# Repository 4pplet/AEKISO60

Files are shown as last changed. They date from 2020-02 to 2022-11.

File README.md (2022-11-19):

# AEKISO60

AEKISO60 is a PCB for use of AEK ISO keycaps in 60% builds, there is some compatibility issues with tray-mount cases due to the AEK ISO layout: Only the mounting hole under space and the ones at the sides can be used. See Altium view of PCB.

## Some features:
- QMK
- USB C
- RGB underglow
- USB horizontal placement is classic GH60, same as GH60, plain60, voyager60 etc.
- ISO AEK Layout support with extensive bottom row support

## Availability:
As an option to DIY, I'll try and keep these available for purchase here: https://4pplet.com/ For DIY, the production files are avaliable in releases.

## Altium view of PCB
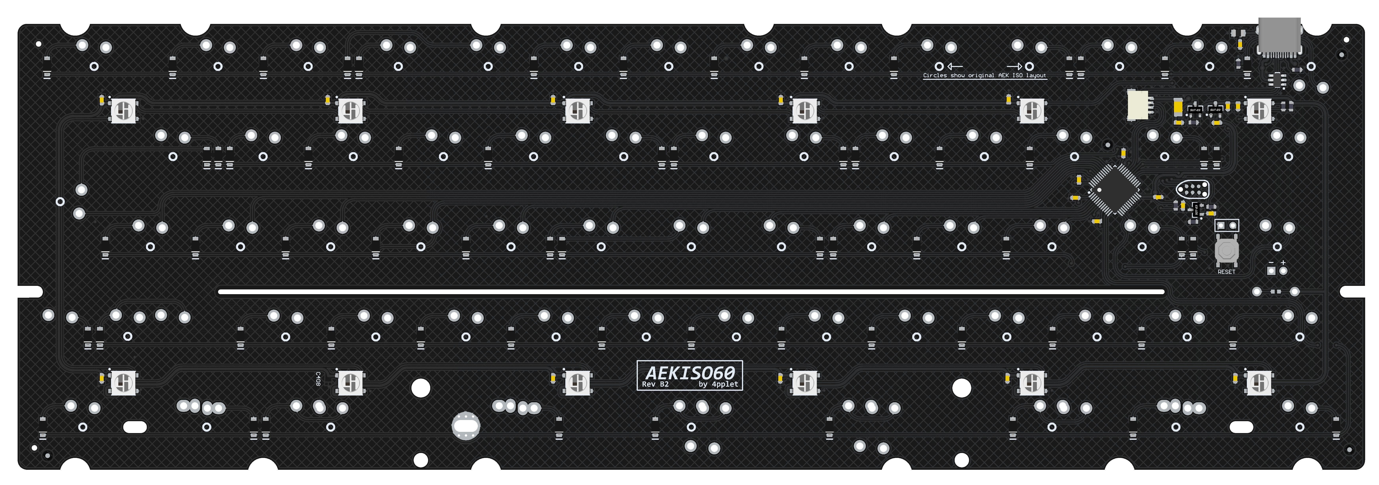
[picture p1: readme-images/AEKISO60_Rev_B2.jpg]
PCB View - Rev B


## Layout support: 
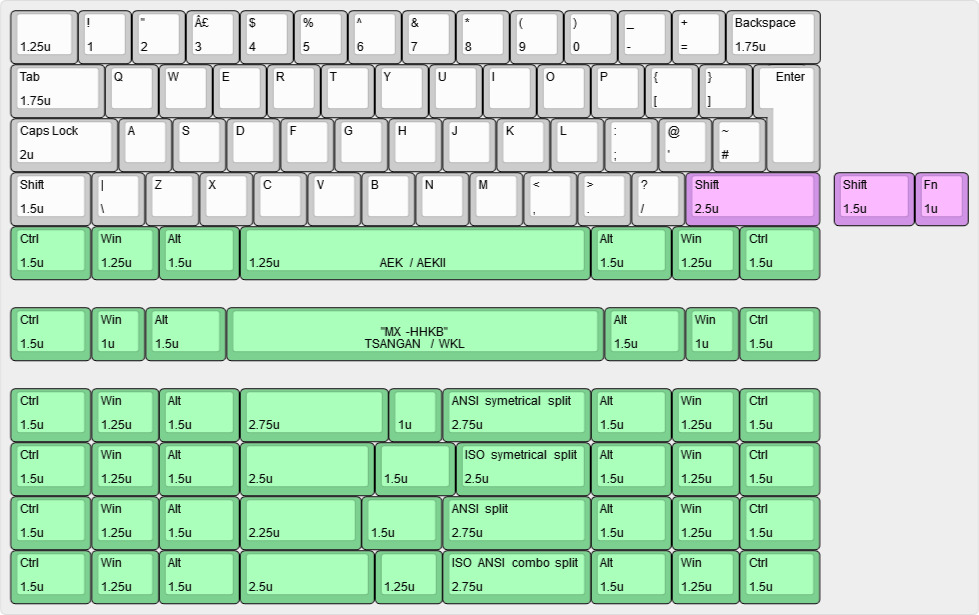
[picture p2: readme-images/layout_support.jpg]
Layout support


## Plate-instruction:
The capslock stabilizer is rotated to give space for the tray-mount screw opening in the plate. Here is a video and picture demonstrating how the stabilizer should be mounted: https://imgur.com/a/tCZg3jl Credits to huygn for making it.

## Revisions:
- Rev A1: Initial prototype
- Rev A2: Improved routing, alligned PCB outline and port position with the other projects. Changed ESD-protection, diodes and XTAL for better compatibility with JLC SMD library.
- Rev A3: Moved daughter board connector to allign with my other 60% projects (same position as cyber60, steezy60 and waffling60-solder)
- Rev A4: Moved daughter board connector for better fitment in bakeneko. Added cutout for bakeneko V3 (untested). Minor siklscreen tweaks.
- Rev B1: Changing MCU to APM/STM32F072, adding LED indicator
- Rev B2: Removing designator left on back side of PCB. Moving LED from FN-switch to Capslock-switch.

<a href='https://ko-fi.com/4pplet' target='_blank'>Buy Me a Coffee at ko-fi.com

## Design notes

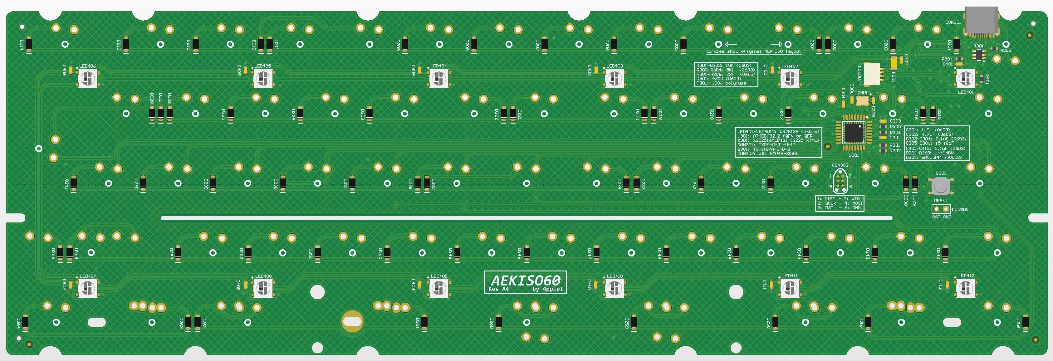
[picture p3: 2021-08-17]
readme-images/AEKISO60_Rev_A4.jpg

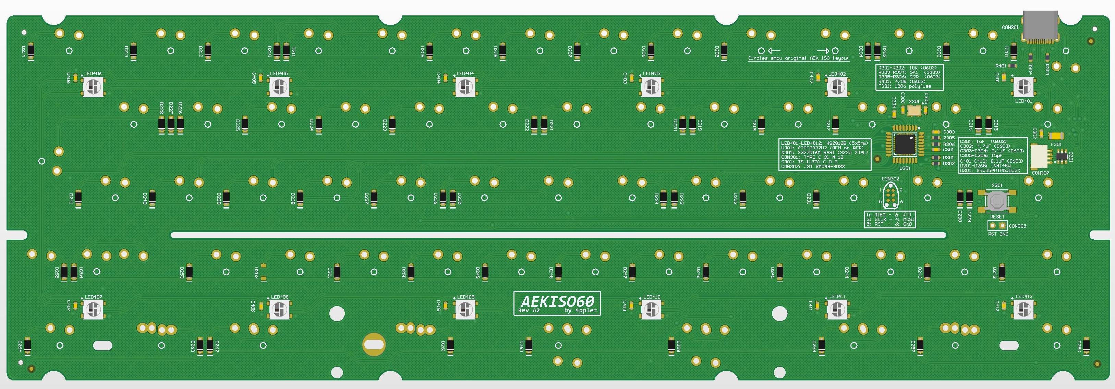
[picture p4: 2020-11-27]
readme-images/AEKISO60_Rev_A2.jpg

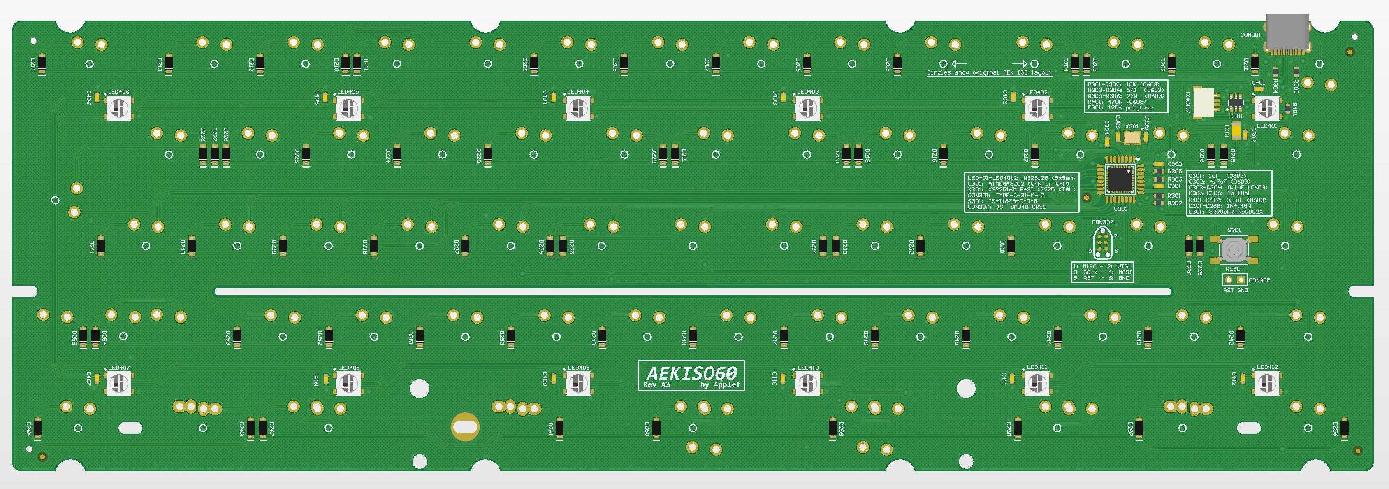
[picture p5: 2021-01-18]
readme-images/AEKISO60_Rev_A3.jpg

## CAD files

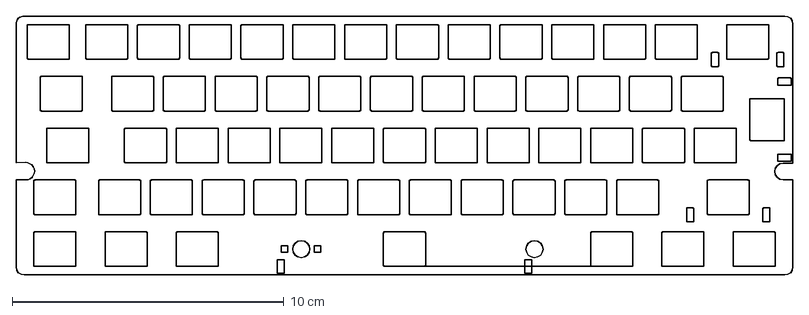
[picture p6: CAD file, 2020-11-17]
AEKISO60_Plate_Rev_A_20201111.dxf
28.6 x 9.53 cm

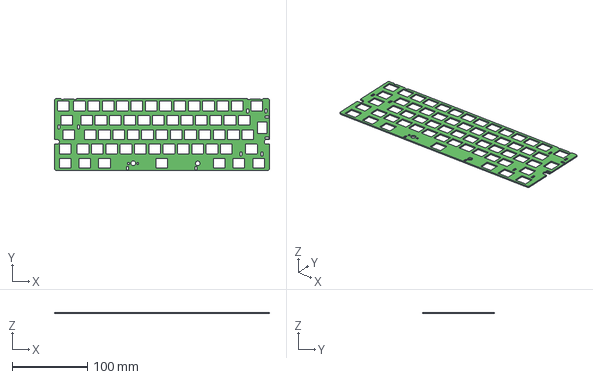
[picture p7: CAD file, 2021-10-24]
Plates/AEKISO60_Plate_Rev_B_FR4.step
285.8 x 95.3 x 1.59 mm

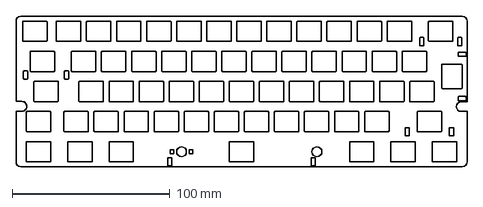
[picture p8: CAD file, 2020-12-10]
Plates/AEKISO60_Plate_Rev_B.dxf
285.8 x 95.2 mm

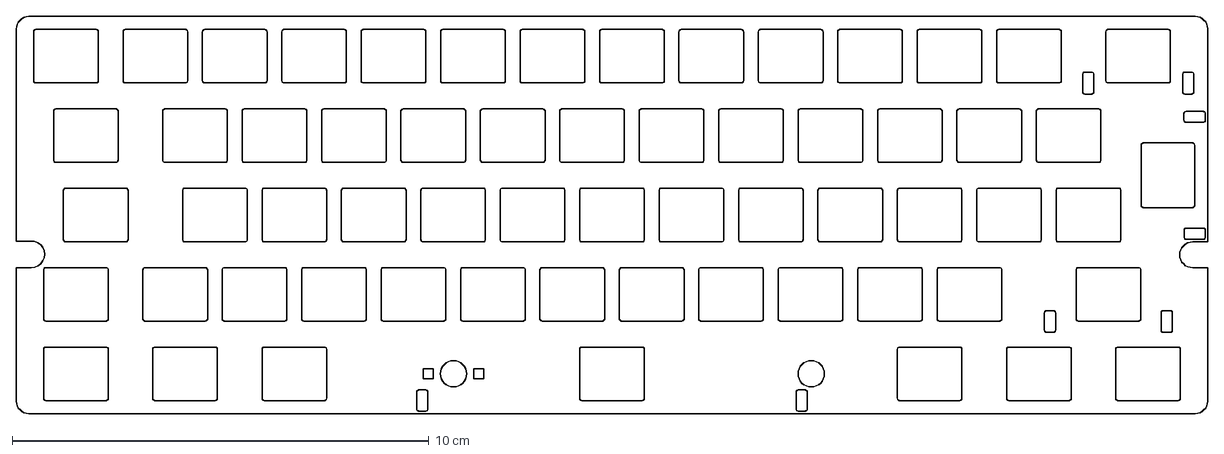
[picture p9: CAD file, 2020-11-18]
Plates/AEKISO60_Plate_Rev_A_20201118.dxf
28.6 x 9.53 cm

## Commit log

2019-11-27 init repo and start
    init repo and start
    [1_top.SchDoc, 2_matrix.SchDoc, 3_mcu.SchDoc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]
2019-12-01 fixed netlist bug, seems to work now
    fixed netlist bug, seems to work now
    [1_top.SchDoc, 2_matrix.SchDoc, AEKISO60.PrjPcb]
2019-12-01 rough implementation done, this should work, need some tidying up
    rough implementation done, this should work, need some tidying up
    [3_mcu.SchDoc, AEKISO60.PcbDoc, AEKISO60.PrjPcb]
2019-12-01 still need to figure out ISO-enter switch position
    still need to figure out ISO-enter switch position
    [2_matrix.SchDoc, AEKISO60.PrjPcb]
2019-12-01 Updated switch and diode numbering, fixed apple logo
    Updated switch and diode numbering, fixed apple logo
    [2_matrix.SchDoc]
2019-12-13 Started to update pinout for underglow leds
    Started to update pinout for underglow leds
    [4_periferals.SchDoc]
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2020-01-16 Started to add JST connector for USB
    Started to add JST connector for USB
    [3_mcu.SchDoc]
2020-01-17 Added LCSC numbers
    Added LCSC numbers
    [3_mcu.SchDoc]
2020-02-03 Updated bottom row with changed layout support
    Updated bottom row with changed layout support
    [2_matrix.SchDoc]
2020-02-04 Files ready for initial prototype
    Files ready for initial prototype
    [AEKISO60.PcbDoc, AEKISO60.PrjPcb]
2020-02-04 Updated BOM
    Updated BOM
    [3_mcu.SchDoc, 4_periferals.SchDoc, AEKISO60.PcbDoc]
2020-02-05 made schematic prettier
    made schematic prettier
    [3_mcu.SchDoc]
2020-02-07 removed second ICSP header, replaced with reset button
    removed second ICSP header, replaced with reset button
    [3_mcu.SchDoc, AEKISO60.PcbDoc]
2020-02-14 added schematic output
    added schematic output
    [3_mcu.SchDoc, AEKISO60.PcbDoc]
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2020-02-22 moved isp pinout on bottom overlay
    moved isp pinout on bottom overlay
    [AEKISO60.PcbDoc]
2020-02-22 updated silkscreen to be in line with other projects
    updated silkscreen to be in line with other projects
    [AEKISO60.PcbDoc]
2020-02-22 moved vias to make silkscreen look better
    moved vias to make silkscreen look better
    [AEKISO60.PcbDoc]
2020-03-08 updated switch-footprint to combo
    updated switch-footprint to combo
    [3_mcu.SchDoc, AEKISO60.PcbDoc]
2020-03-25 Started revision B1, added capslock LED
    Started revision B1, added capslock LED
    [1_top.SchDoc, 2_matrix.SchDoc, 3_mcu.SchDoc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]
2020-03-25 removed THT icsp header and extra reset button
    removed THT icsp header and extra reset button
    [3_mcu.SchDoc, AEKISO60.PcbDoc]
2020-03-25 forgot to save
    forgot to save
    [3_mcu.SchDoc, AEKISO60.PcbDoc]
2020-03-30 removed pad-opening in top-solder for switches, moved usb-connector out a bit
    removed pad-opening in top-solder for switches, moved usb-connector out a bit
    [3_mcu.SchDoc, AEKISO60.PcbDoc]
2020-03-31 started adding flexcut
    started adding flexcut
    [AEKISO60.PcbDoc]
2020-04-01 DRC ok, routing decent. First draft of B1 release
    DRC ok, routing decent. First draft of B1 release
    [AEKISO60.PcbDoc]
2020-04-12 added tooling holes
    added tooling holes
    [AEKISO60.PcbDoc]
2020-04-12 removed tenting
    removed tenting
    [AEKISO60.PcbDoc]
2020-04-23 Restored flex cut, but 1.5mm
    Restored flex cut, but 1.5mm
    [AEKISO60.PcbDoc]
2020-04-24 updated with verified iso enter and removed unaccessible mouting holes
    updated with verified iso enter and removed unaccessible mouting holes
    [AEKISO60.PcbDoc]
2020-04-24 updated parameters and output file, updated readme pic
    updated parameters and output file, updated readme pic
    [2_matrix.SchDoc, 3_mcu.SchDoc, 4_periferals.SchDoc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]
2020-04-24 tweaked routing a bit
    tweaked routing a bit
    [AEKISO60.PcbDoc]
2020-04-26 minor update
    [AEKISO60.PcbDoc]
2020-06-27 tiny tweak
    [AEKISO60.PcbDoc]
2020-06-30 minor tweaks
    [AEKISO60.PcbDoc]
2020-07-09 scrapped B-revision, returning to A
    [1_top.SchDoc, 2_matrix.SchDoc, 3_mcu.SchDoc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]
2020-07-09 DRC ok
    [2_matrix.SchDoc, 3_mcu.SchDoc, AEKISO60.PcbDoc]
2020-07-09 minor tweak
    [AEKISO60.PcbDoc, AEKISO60.PrjPcb]
2020-07-24 started changing diodes to common
    [2_matrix.SchDoc, AEKISO60.PcbDoc]
2020-08-09 DRC OK, should be done for protos
    [AEKISO60.PcbDoc]
2020-09-07 started switching out the diodes
    [2_matrix.SchDoc, 3_mcu.SchDoc, AEKISO60.PcbDoc]
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2020-09-07 DRC ok, diodes replaced
    [2_matrix.SchDoc, AEKISO60.PcbDoc]
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2020-09-21 DRC OK, Rev A2 is pretty much done here.
    [AEKISO60.PrjPcb]
2020-09-21 fixed spacing of underglow leds. DRC OK
2020-09-21 fixed conflicting silkscreen designator
2020-09-23 changed reset switch footprint under space
    [3_mcu.SchDoc, AEKISO60.PrjPcb]
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2020-09-26 added component values, added 3D-model for XTAL
    [3_mcu.SchDoc]
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2020-09-28 changed diode in bom to a more common one
    changed diode in bom to a more common one
    [2_matrix.SchDoc]
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2020-11-18 updated plate, had an extra line
    [AEKISO60_Plate_Rev_A_20201118.dxf]
2020-11-21 minor trace tweak for enter switch and S254
    minor trace tweak for enter switch and S254
    [2_matrix.SchDoc]
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2020-12-01 Create AEKISO60_Plate_Rev_B.dxf
    Includes Caplocks stabs cutouts
    [AEKISO60_Plate_Rev_B.dxf]
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2021-01-08 Updated info on schematic
    [1_top.SchDoc, 2_matrix.SchDoc, 3_mcu.SchDoc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]
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2021-10-01 moving plates into their own dir
    [AEKISO60_Plate_Rev_A_20201118.dxf, AEKISO60_Plate_Rev_B.dxf]
2021-10-24 adding FR4-plate
    adding FR4-plate
    [AEKISO60_Plate_Rev_B_FR4.step]
2022-02-21 moving stuff from keeb-lib into a aekiso60 lib
    [aekiso60.PcbLib]
2022-09-13 files for pre-release 20220913
    [1_top.SchDoc, 4_periferals.SchDoc, AEKISO60.PcbDoc]
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
